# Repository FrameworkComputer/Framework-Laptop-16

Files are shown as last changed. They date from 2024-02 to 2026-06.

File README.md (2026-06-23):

# Framework Laptop 16
Documentation around the Mainboard and other key parts of Framework Laptop 16 
(available at https://frame.work/marketplace/mainboards).

We designed Framework Laptop 16 to enable re-use of key modules like the Mainboard.
The Mainboard is operable as a standalone single board computer outside of the laptop,
though with kind of a large form factor relative to Framework Laptop 13.

## License

Framework Laptop 16 © 2024 by Framework Computer Inc is licensed under CC BY 4.0.
To view a copy of this license, visit http://creativecommons.org/licenses/by/4.0/

## 3D CAD (in the base directory)

External 3D CAD of the system and main modules to enable development of 3D-printed replacement parts,
skins, cases, and other accessories.  We're excited to see what you do with it!

## Case

This folder contains a 3D printable case to reuse the Mainboard as a standalone computer.

## Mainboard

This folder contains 2D drawings and interface schematics to enable Mainboard re-use.

## Touchpad

This folder contains 3D printable CAD for single-piece replacement versions of the Touchpad row.

## Input Modules

See https://github.com/FrameworkComputer/InputModules

## Expansion Bay

See https://github.com/frameworkComputer/ExpansionBay

## Expansion Cards

See https://github.com/frameworkComputer/ExpansionCards

## Webcam

See https://github.com/FrameworkComputer/Framework-Laptop-13/tree/main/Webcam

## Display

Pinout of the Display to enable re-use.

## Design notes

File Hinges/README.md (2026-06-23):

Available at https://frame.work/products/16-hinge-kit

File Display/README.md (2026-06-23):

# Display

## License

Framework Laptop 16 © 2023-2026 by Framework Computer Inc is licensed under CC BY 4.0.
To view a copy of this license, visit http://creativecommons.org/licenses/by/4.0/

## Pinout

| Pin | Signal | Notes | Diff vs Laptop 13 |
|-----|---|---|---|
| 1 | DDS SCL | Nvidia DDS I2C SCL | Added |
| 2 | GND | Signal ground | |
| 3 | EDP_TXN_3 | | |
| 4 | EDP_TXP_3 | | |
| 5 | GND | Signal ground | |
| 6 | EDP_TXN_2 | | |
| 7 | EDP_TXP_2 | | |
| 8 | GND | Signal ground | |
| 9 | EDP_TXN_1 | | |
| 10  | EDP_TXP_1 | | |
| 11  | GND | Signal ground | |
| 12  | EDP_TXN_0 | | |
| 13  | EDP_TXP_0 | | |
| 14  | GND | Signal ground | |
| 15  | AUXP | | |
| 16  | AUXN | | |
| 17  | GND | Signal ground | |
| 18  | 3V_EDP | 3.3V typical | |
| 19  | 3V_EDP | 3.3V typical | |
| 20  | 3V_EDP | 3.3V typical | |
| 21  | 3V_EDP | 3.3V typical | |
| 22  | SELF_TEST | Self test enable | |
| 23  | GND | Digital ground | |
| 24  | GND | Digital ground | |
| 25  | GND | Digital ground | |
| 26  | GND | Digital ground | |
| 27  | EDP_HPD | Hot plug detect output | |
| 28  | GND | Backlight ground | |
| 29  | GND | Backlight ground | |
| 30  | GND | Backlight ground | |
| 31  | GND | Backlight ground | |
| 32  | BLK_OFF_N | 3.3V input | |
| 33  | BLK_PWM_LCD | 200Hz to 2kHz, 3.3V | |
| 34  | DDS SDA | Nvidia DDS I2C SDA | Added |
| 35  | PSR_EN# | Panel-Self-Refresh | Added |
| 36  | BL_POWER | 5V-21V | |
| 37  | BL_POWER | 5V-21V | |
| 38  | BL_POWER | 5V-21V | |
| 39  | BL_POWER | 5V-21V | |
| 40  | OD_EN | | Added |

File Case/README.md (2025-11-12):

# Framework Laptop 16 Case
This is a 3D-printable case to enable re-use of the Framework Laptop 16 Mainboard.

Note that you'll want to use filament that is designed for high temperatures, like ABS, PETG, or PP.

It is sized to be able to fit on the print bed of a Prusa XL, but there is also a split
version to enable smaller printers.

You'll need to print 8x of the "Connect Pin 1" to connect the top and bottom halves to each other.

If you're printing the split version, you'll also need 5x of the "Connect Pin 2".



## License

Framework Laptop 16 © 2024 by Framework Computer Inc is licensed under CC BY 4.0.
To view a copy of this license, visit http://creativecommons.org/licenses/by/4.0/

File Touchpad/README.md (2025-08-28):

# Touchpad


## License

Framework Laptop 16 © 2025 by Framework Computer Inc is licensed under CC BY 4.0.
To view a copy of this license, visit http://creativecommons.org/licenses/by/4.0/

## 3D CAD

This is 3D printable CAD of a single-piece alternative to the three-piece touchpad row
on Framework Laptop 16.
The best orientation to print this, is with the flat side (where the palms
would rest) on the bottom facing the printer bed.

You can directly unscrew the Touchpad Module itself and the daughterboard and screw them
into the 3D printed plastic parts.  Be careful not to over-tighten the fasteners, since
you can strip the plastic.

Make sure you align the Touchpad Module in the center of the opening.  You can do this easily
by screwing in one fastener, then flipping the assembly over, aligning it, and then holding it place,
flipping it back over, and screwing in the remaining fasteners.

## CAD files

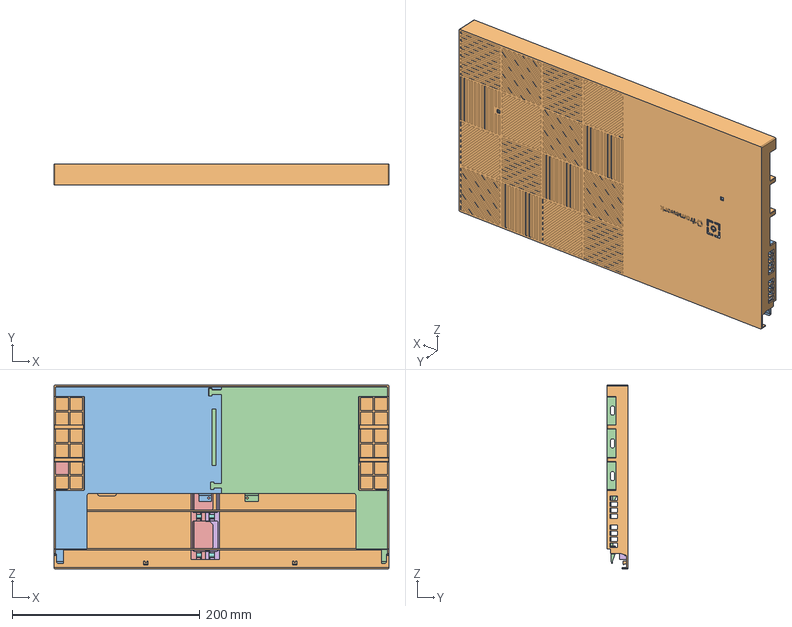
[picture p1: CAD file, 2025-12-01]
Case/mb_case_assy_11112025.stp
356.6 x 22.1 x 195.5 mm
MB_CASE_BOTTOM_COVER
MB_CASE_TOP_COVER
MB_CASE_BOTTOM_COVER_LEFT
MB_CASE_BOTTOM_COVER_RIGHT
MB_CASE_TOP_COVER_LEFT
MB_CASE_TOP_COVER_RIGHT
CONNECT_PIN_1 x 8
CONNECT_PIN_2 x 5

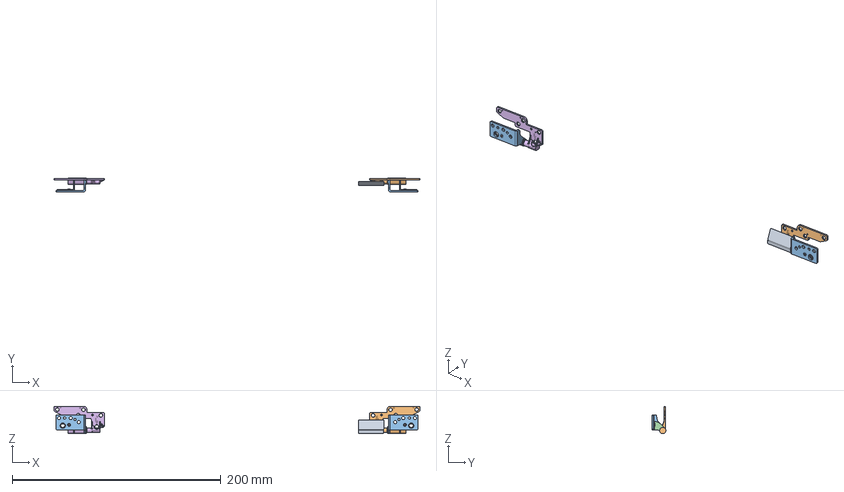
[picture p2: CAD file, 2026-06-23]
Hinges/framework_laptop_16_hinge_assy_asm.stp
350.4 x 13.2 x 26.2 mm
IFGP6_DISPLAY_ASSY_SKEL
IFGP6_LCD_BRACKET_R_3
IFGP6_BASE_BRACKET_R
IFGP6_BASE_BRACKET_R_2
IFGP6_HINGE_RIVET x 2
IFGP6_LCD_BRACKET_L
IFGP6_BASE_BRACKET_L
IFGP6_BASE_BRACKET_L_2

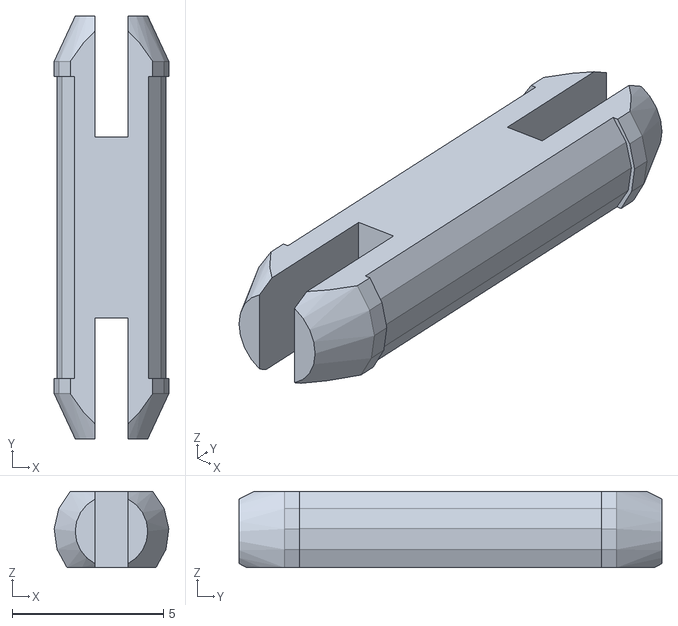
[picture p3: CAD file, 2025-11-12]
Case/Full version/connect_pin_1_11112025.stl
3.80 x 14.0 x 2.52

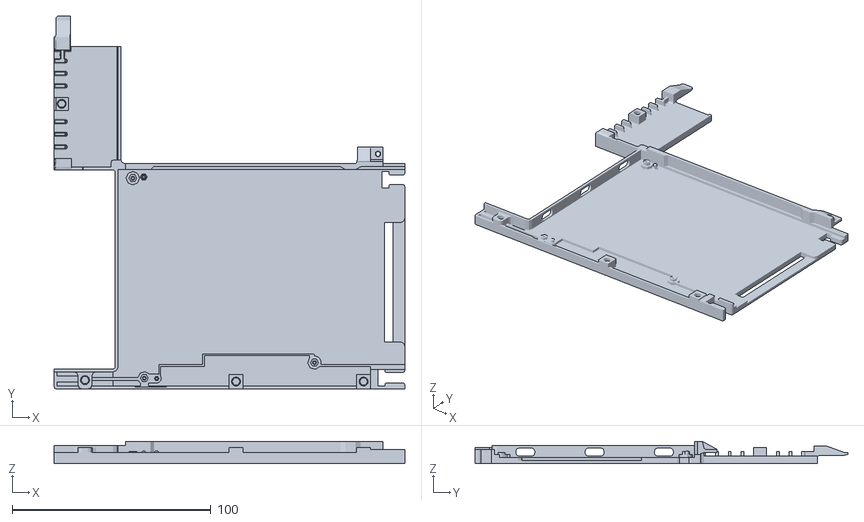
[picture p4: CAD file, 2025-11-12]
Case/Split verstion/mb_case_bottom_cover_left_11112025.stl
176.6 x 187.9 x 11.2

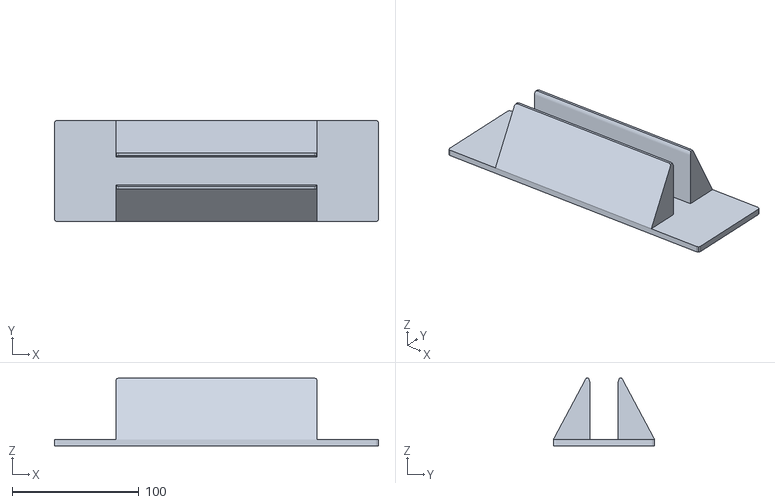
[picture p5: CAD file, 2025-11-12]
Case/Stand/mbcase_id_stand_11112025.stl
255.7 x 80.0 x 53.5

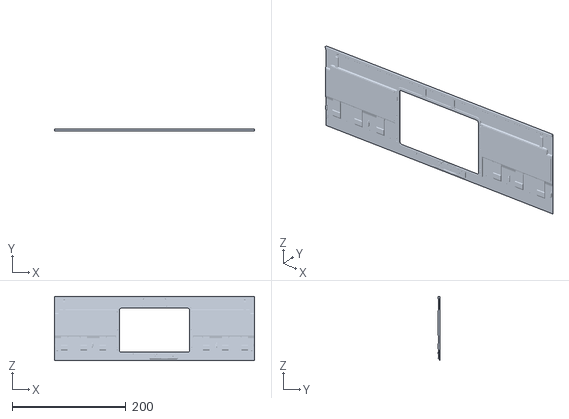
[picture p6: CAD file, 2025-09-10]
Touchpad/one_piece_tp_mid_0909.stl
351.6 x 3.15 x 112.6

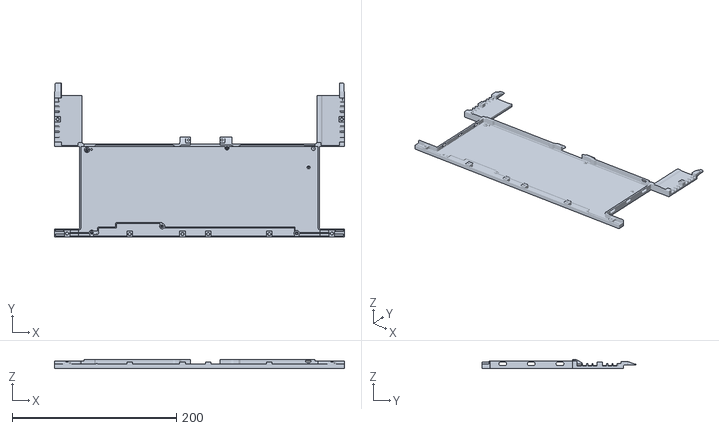
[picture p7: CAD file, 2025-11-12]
Case/Full version/mb_case_bottom_cover_11112025.stl
353.2 x 187.9 x 11.2

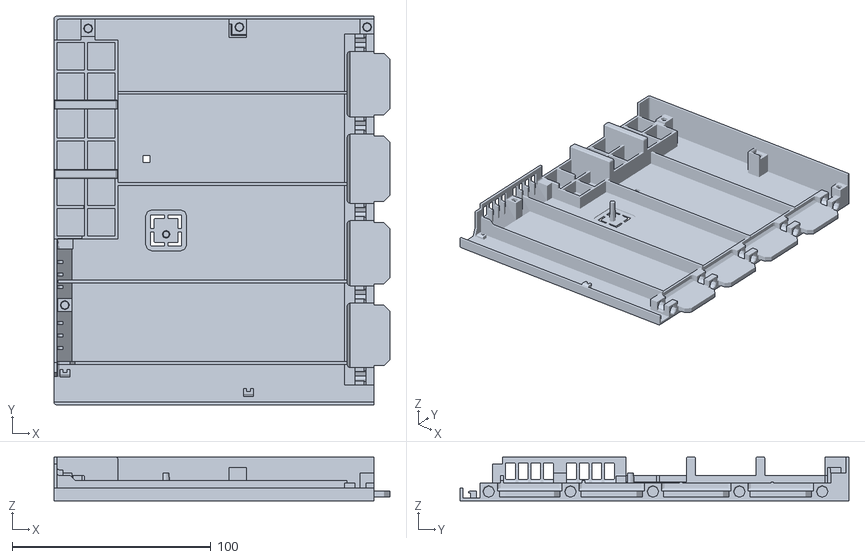
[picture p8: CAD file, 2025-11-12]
Case/Split verstion/mb_case_top_cover_left_11112025.stl
169.1 x 195.5 x 22.0

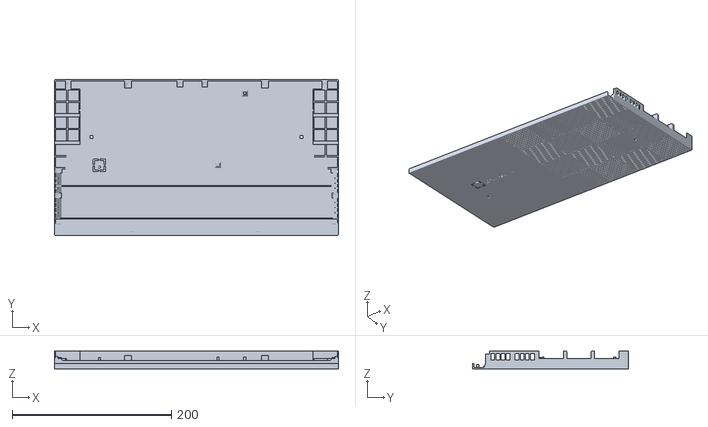
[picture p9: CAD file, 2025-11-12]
Case/Full version/mb_case_top_cover_11112025.stl
356.6 x 195.5 x 22.0

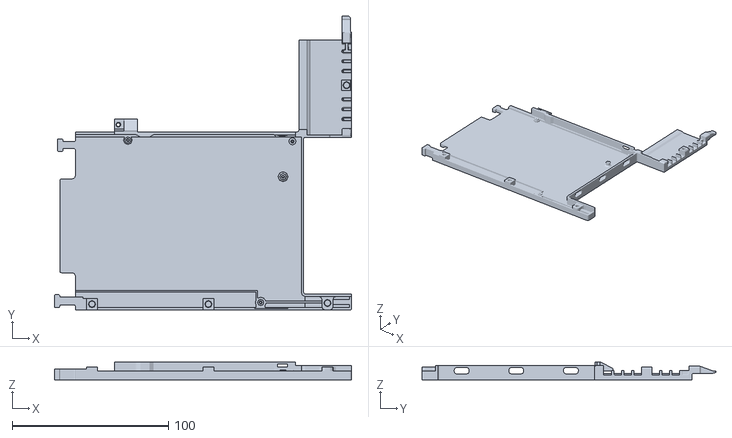
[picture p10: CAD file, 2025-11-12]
Case/Split verstion/mb_case_bottom_cover_right_11112025.stl
190.1 x 187.9 x 11.2

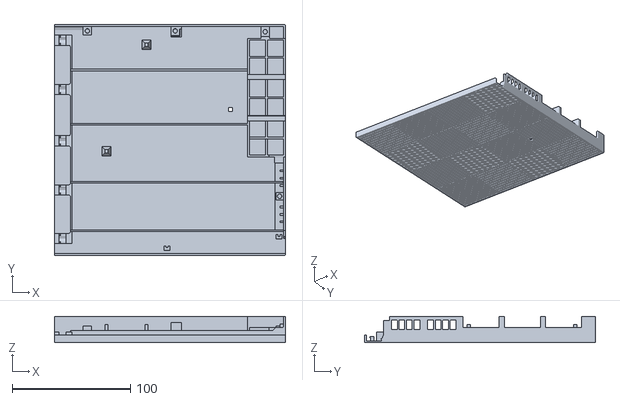
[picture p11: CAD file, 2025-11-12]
Case/Split verstion/mb_case_top_cover_right_11112025.stl
195.5 x 195.5 x 22.0

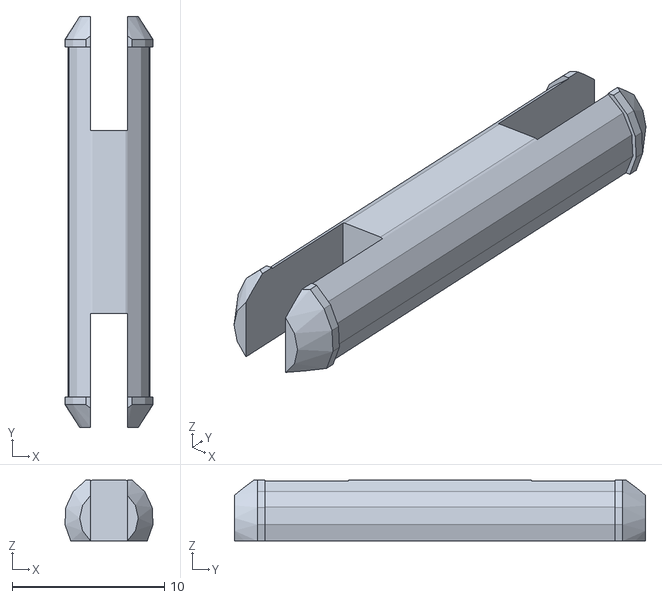
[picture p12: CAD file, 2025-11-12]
Case/Split verstion/connect_pin_2_11112025.stl
5.79 x 27.0 x 4.00

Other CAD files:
Touchpad/one_piece_tp_right_0909.stl
Touchpad/one_piece_tp_left_0909.stl

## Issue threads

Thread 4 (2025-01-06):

Errors in PDF USB Section

hasechris, 2025-01-06:
Hi,

I just looked at the first block level schematic for like an hour and then saw something which I find quite confusing. Please see the image here:

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

Why are only CC-Line Connections mentioned for one USB-C Port? I thougth the PD Controllers would have to be connected to the 4 USB-C Ports which support Power Delivery.

Best regards
hasechris

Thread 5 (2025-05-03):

Framework 16 Panel Pinout Not Documented

ThatWileyGuy, 2025-05-03:
The Framework 13 panel-side eDP pinout is documented at https://github.com/FrameworkComputer/Framework-Laptop-13/blob/main/Display/README.md

I cannot find an equivalent for the Framework 16. I do see the mainboard-side pinout in https://github.com/FrameworkComputer/Framework-Laptop-16/blob/main/Mainboard/Mainboard_Interfaces_Schematic_Framework_Laptop_16_7040_Series.pdf , but it doesn't look like the panel-side pinout is documented?

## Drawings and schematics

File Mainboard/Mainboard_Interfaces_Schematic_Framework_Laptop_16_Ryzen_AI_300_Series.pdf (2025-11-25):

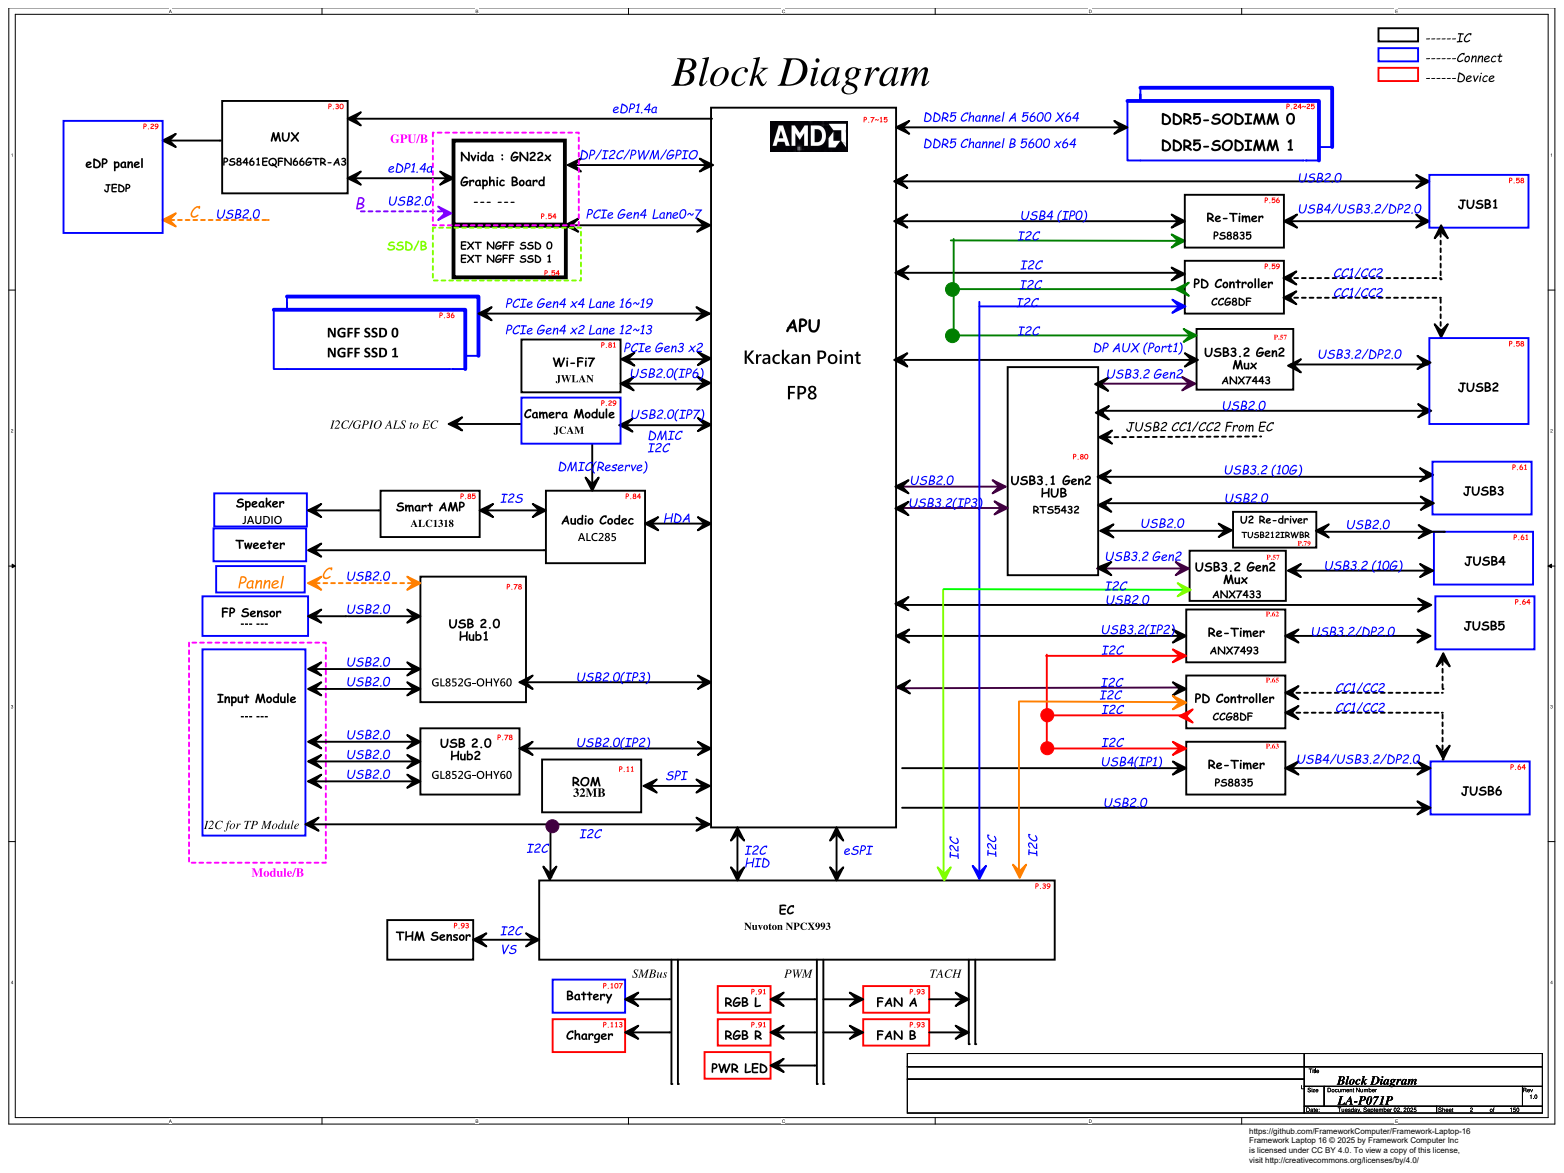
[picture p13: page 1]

https://github.com/FrameworkComputer/Framework-Laptop-16
Framework Laptop 16 © 2025 by Framework Computer Inc
is licensed under CC BY 4.0. To view a copy of this license,
visit http://creativecommons.org/licenses/by/4.0/

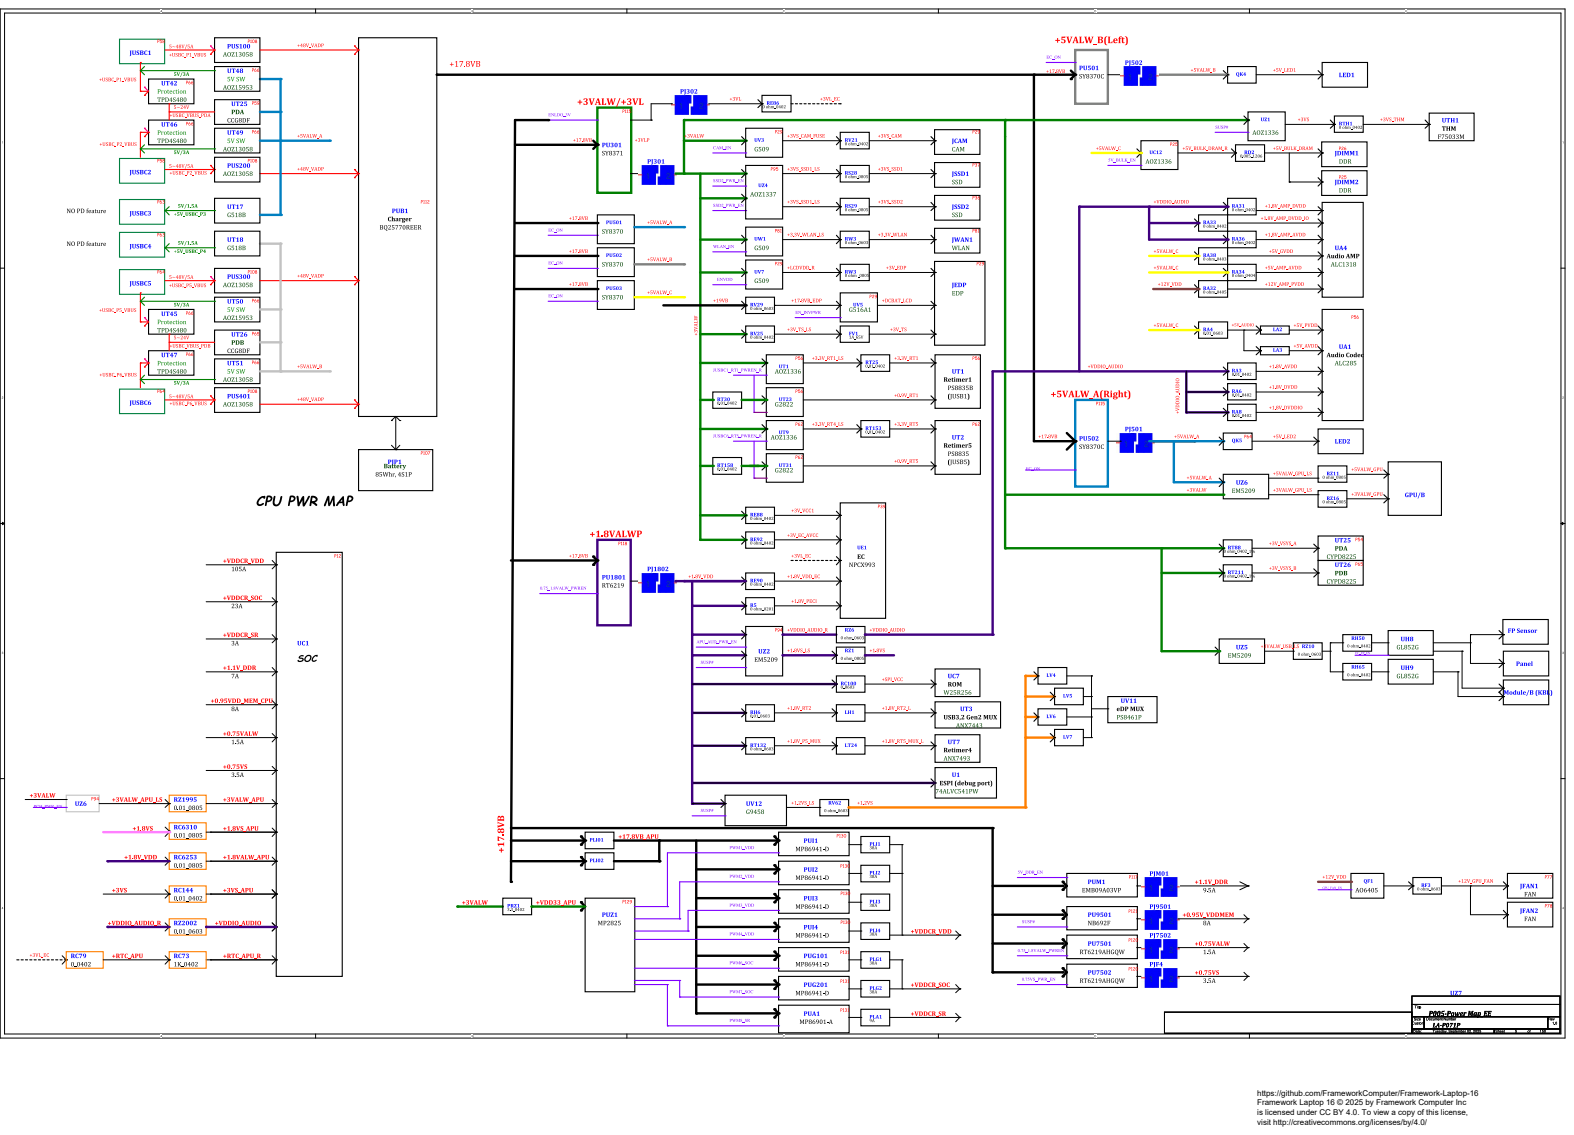
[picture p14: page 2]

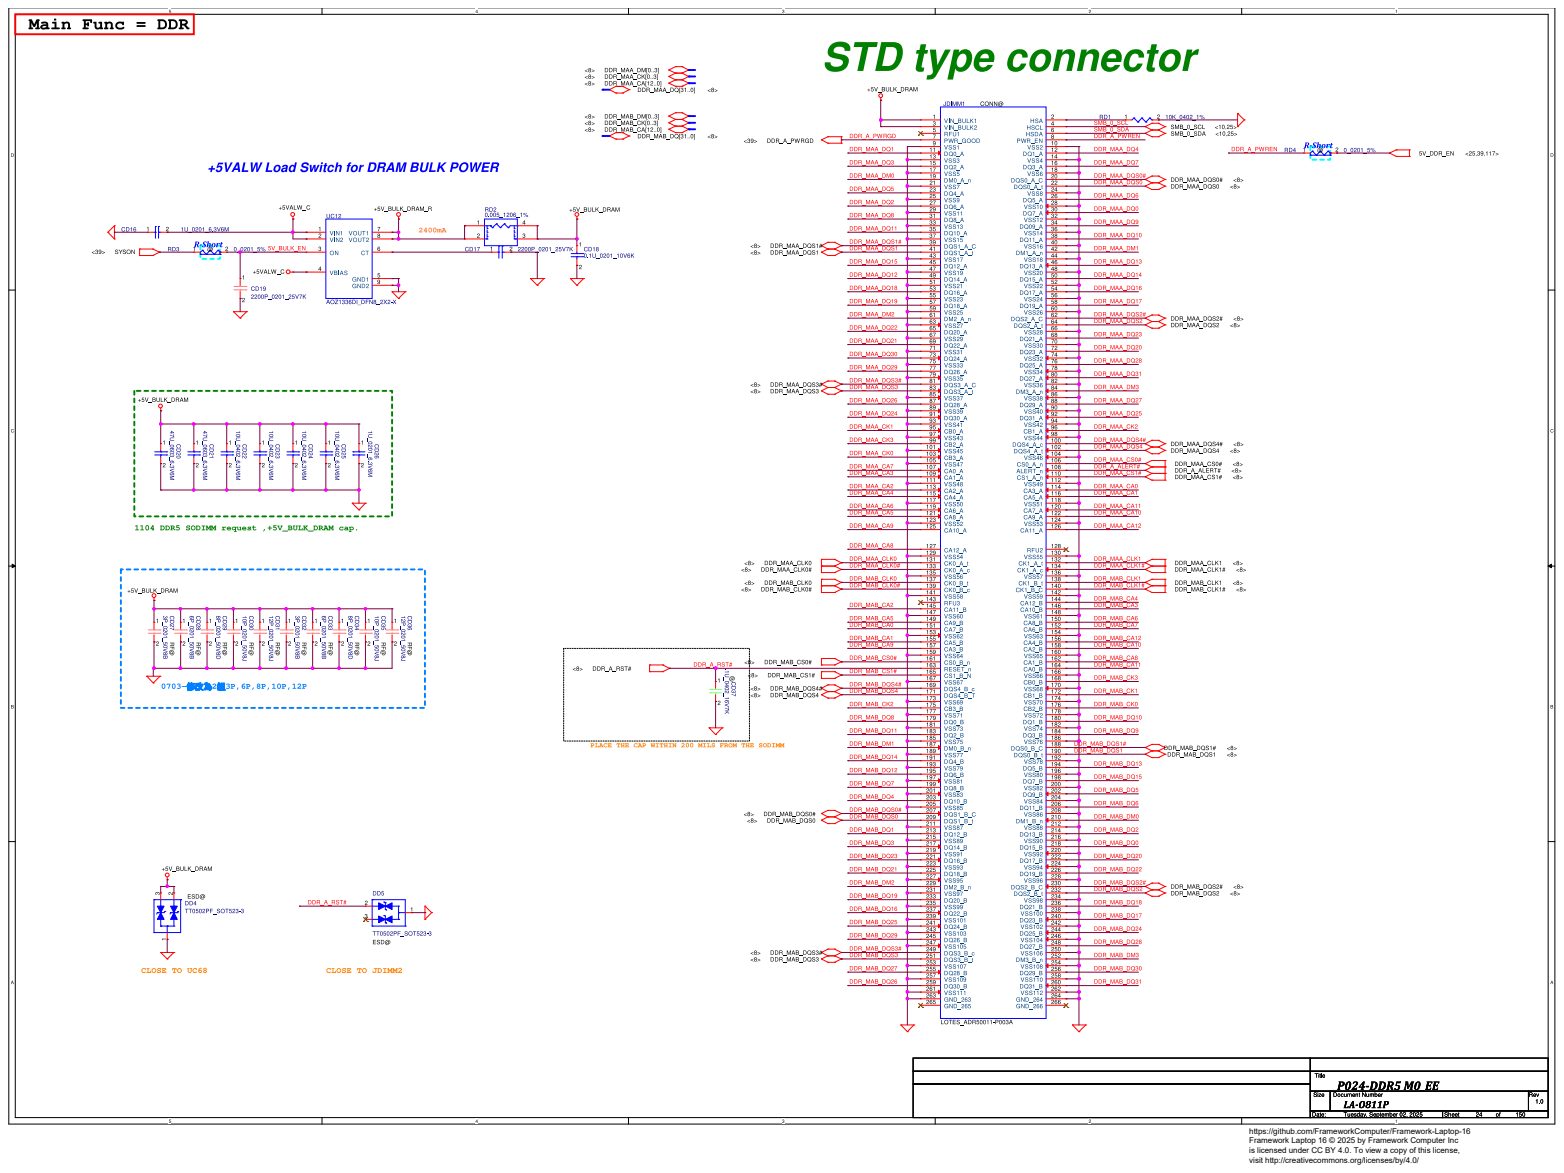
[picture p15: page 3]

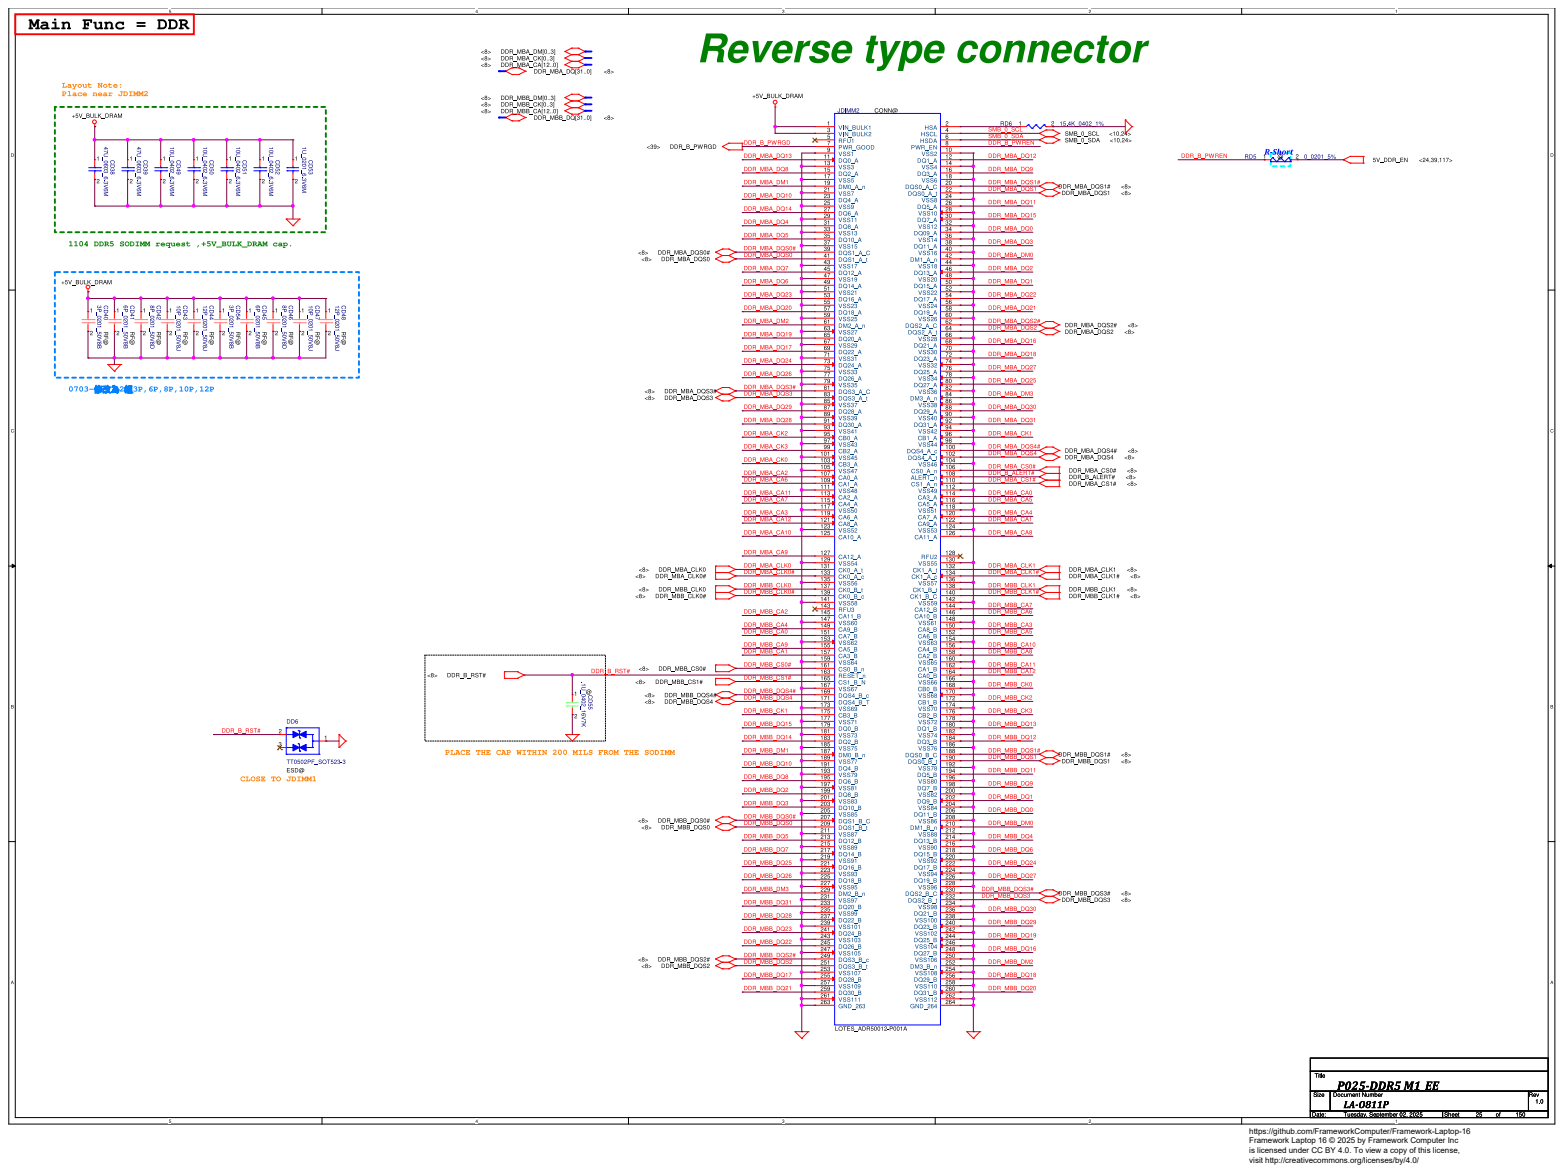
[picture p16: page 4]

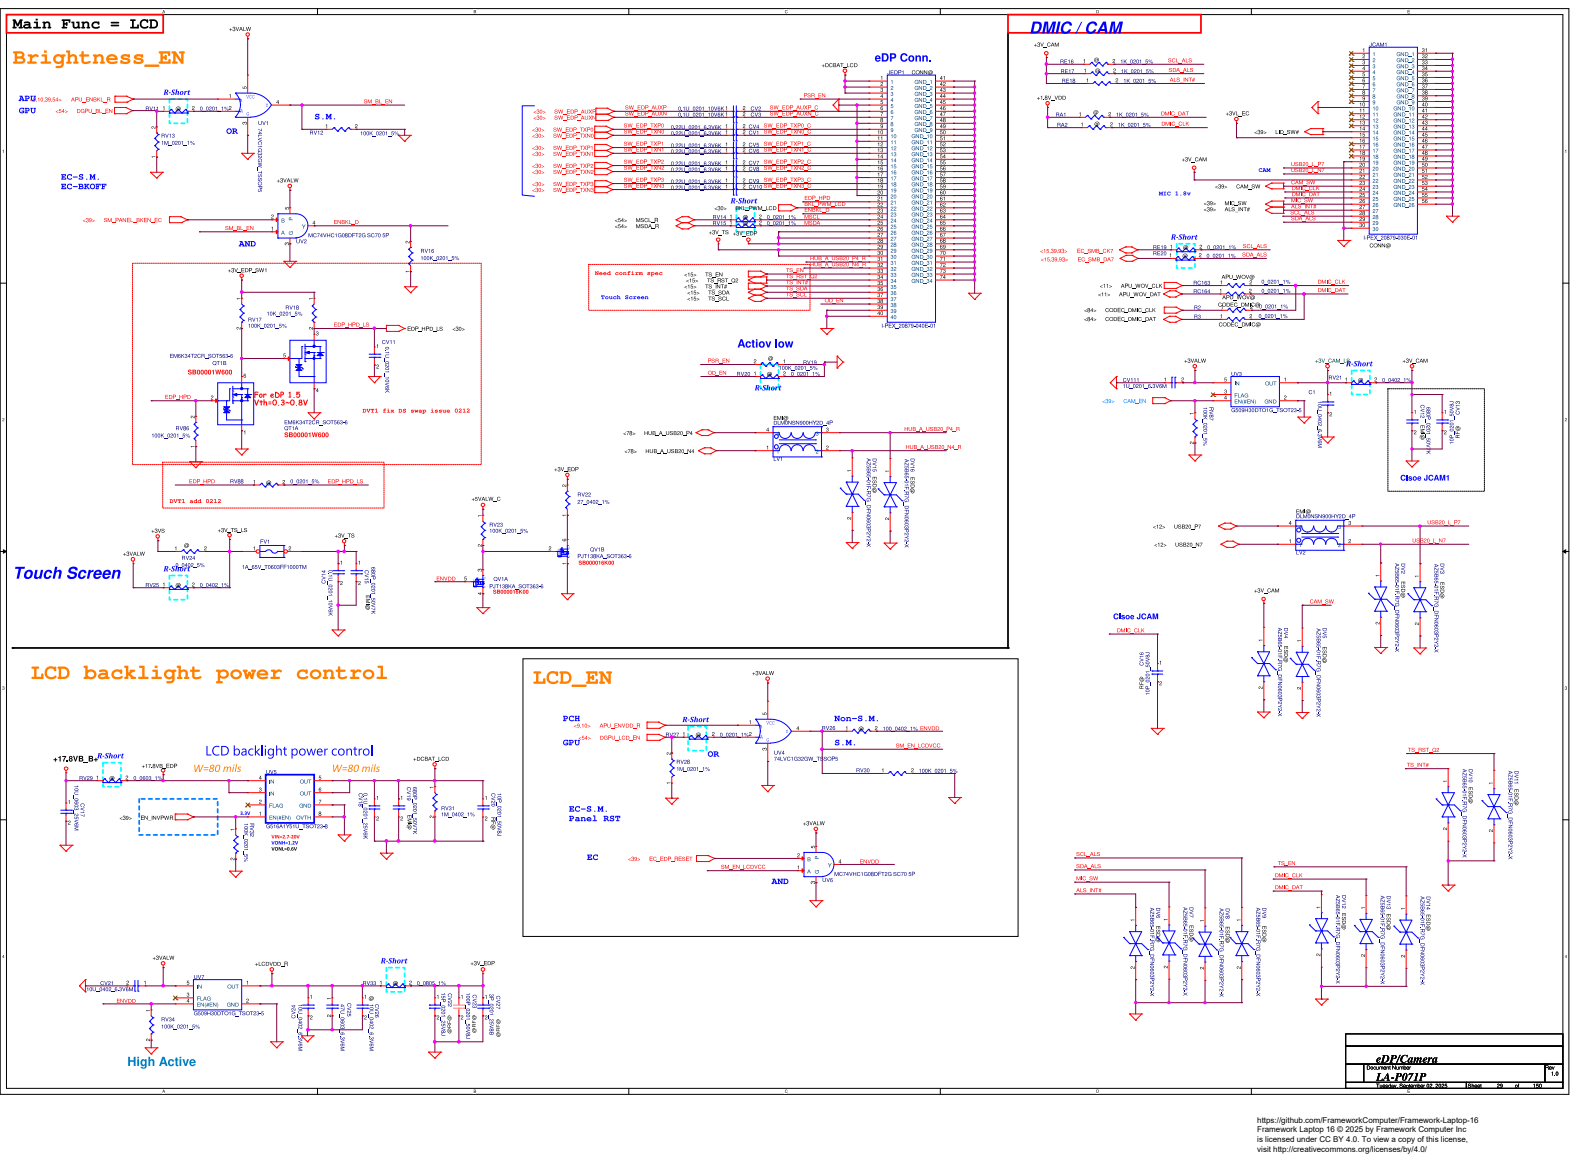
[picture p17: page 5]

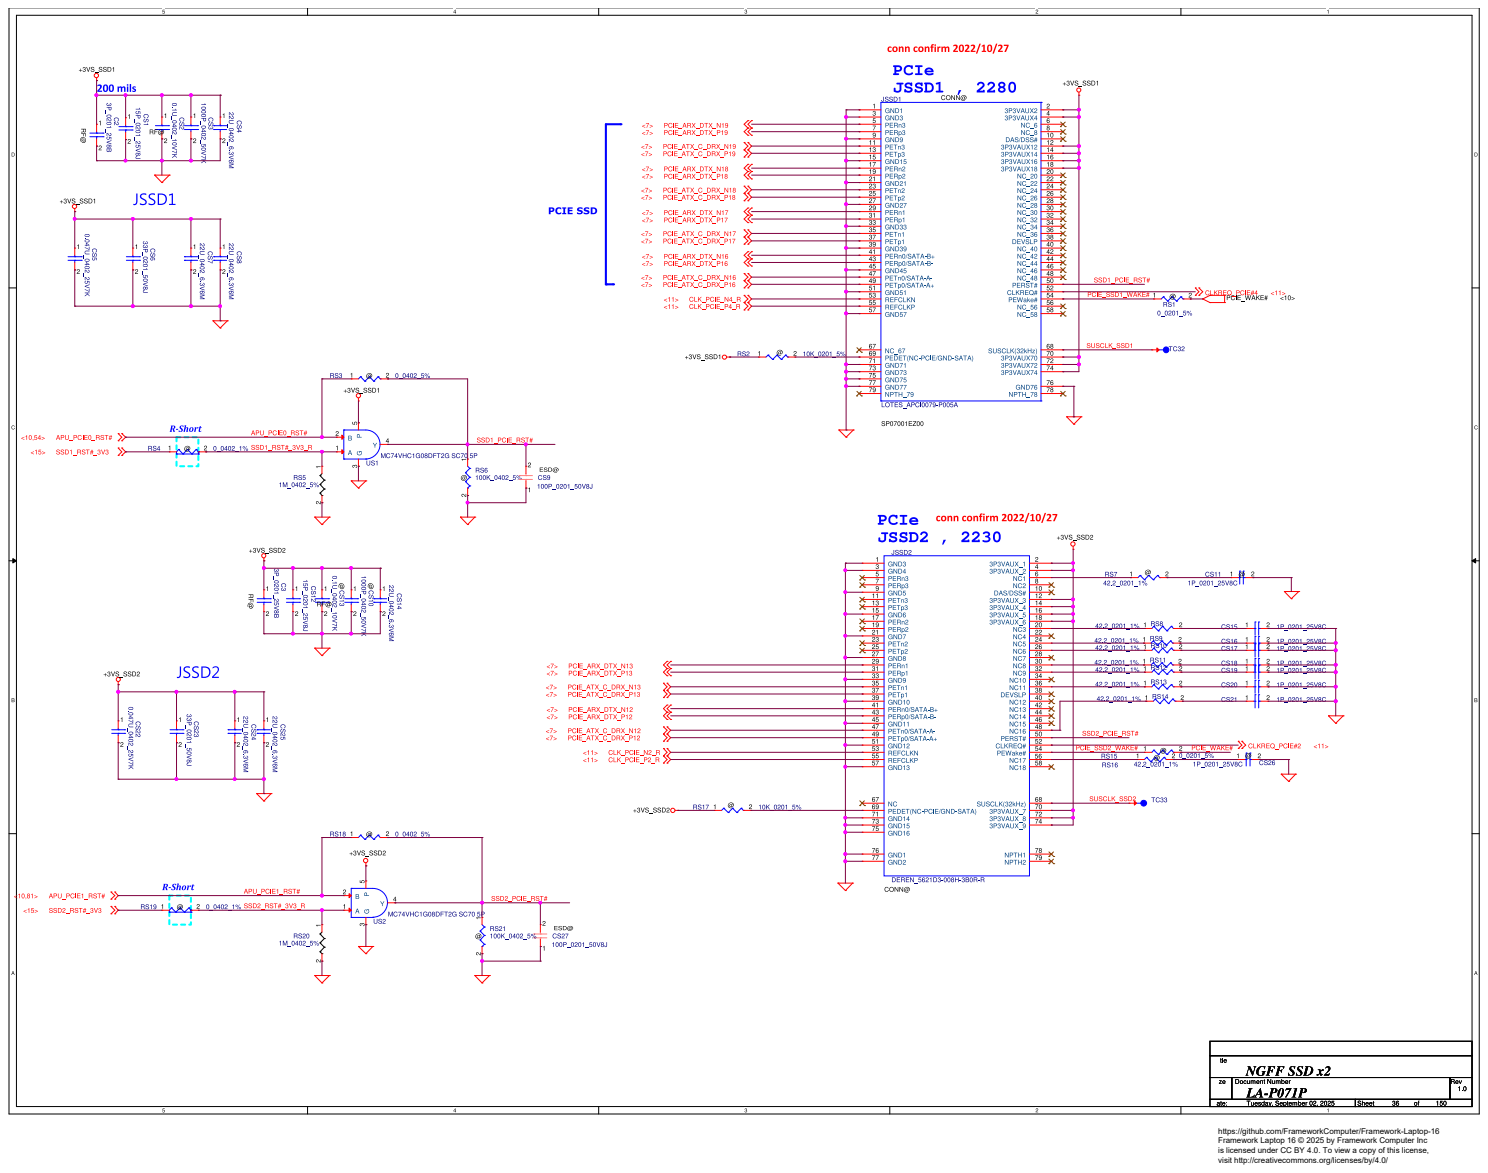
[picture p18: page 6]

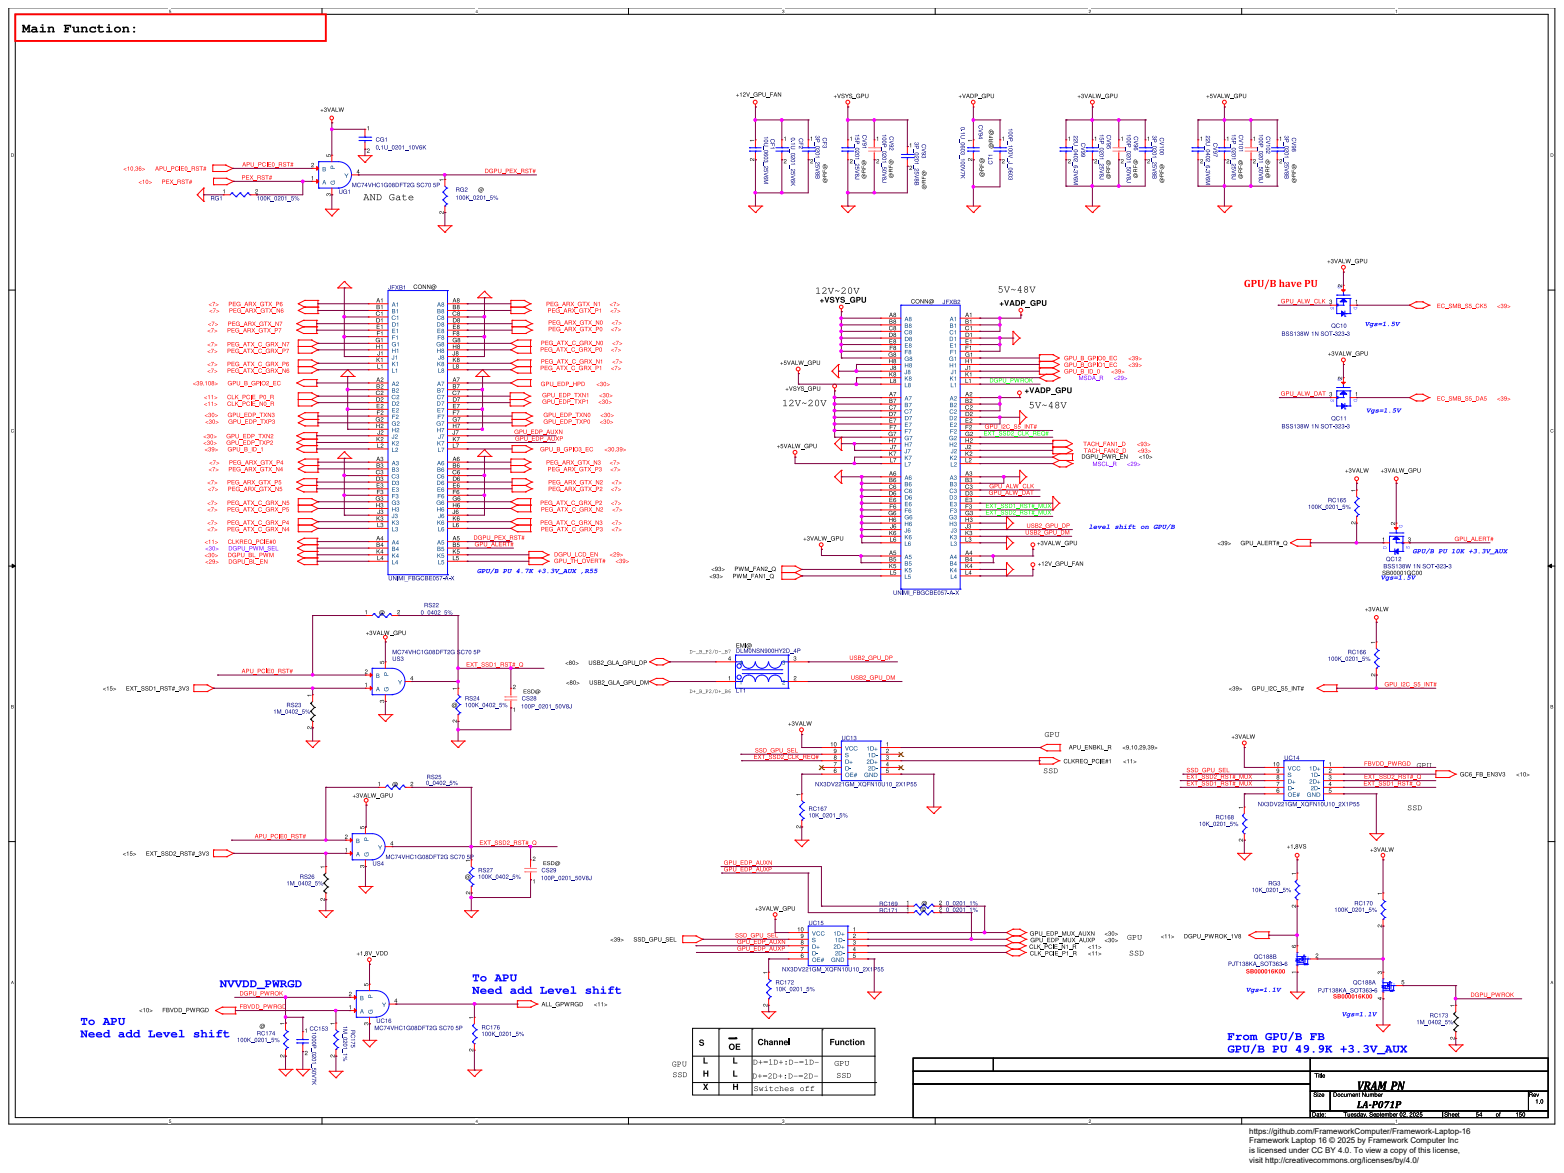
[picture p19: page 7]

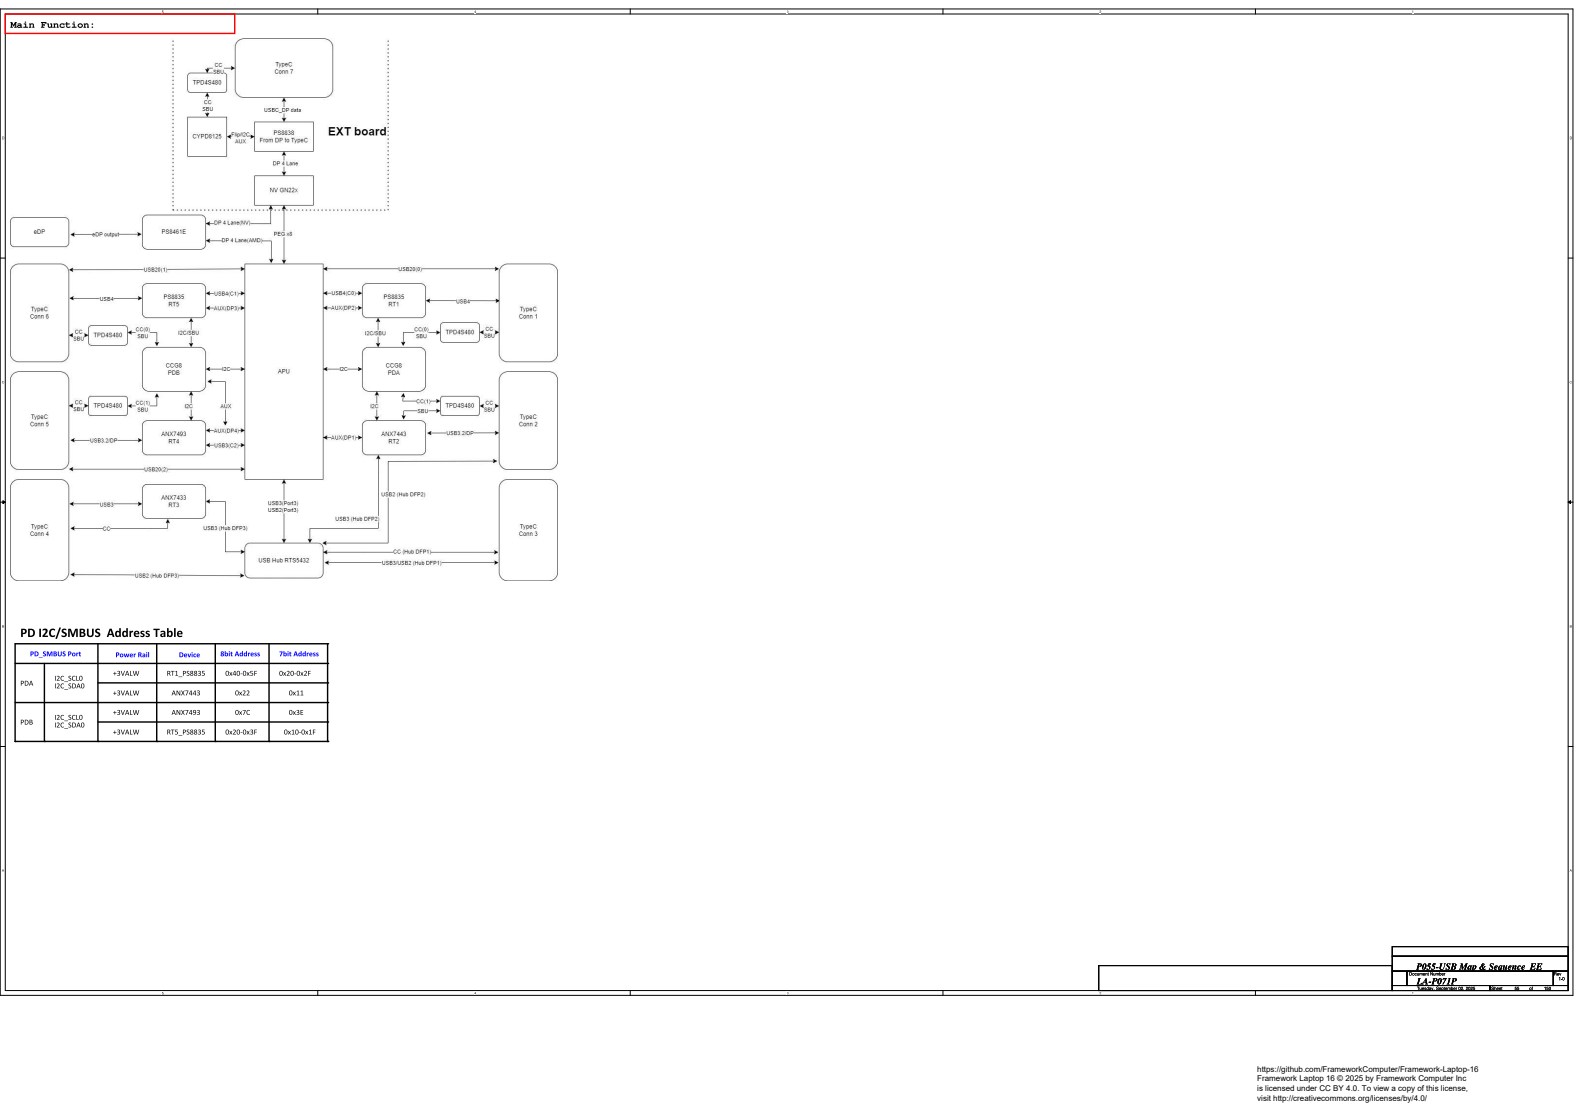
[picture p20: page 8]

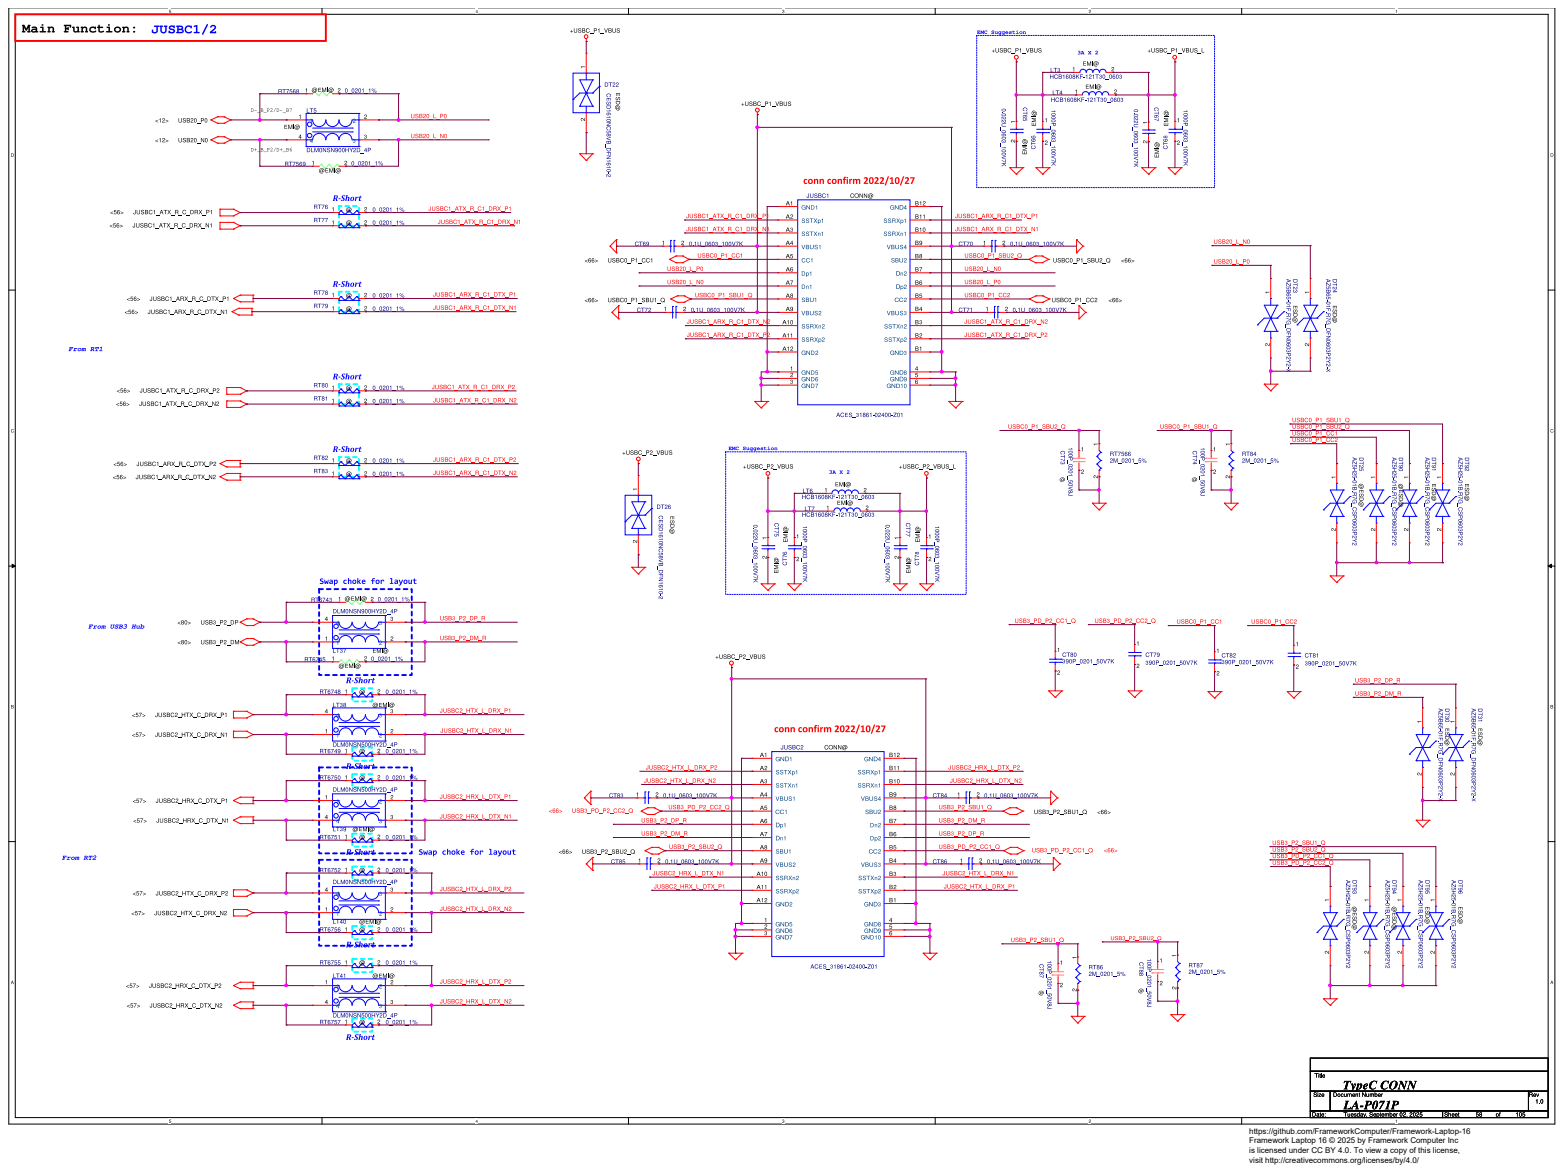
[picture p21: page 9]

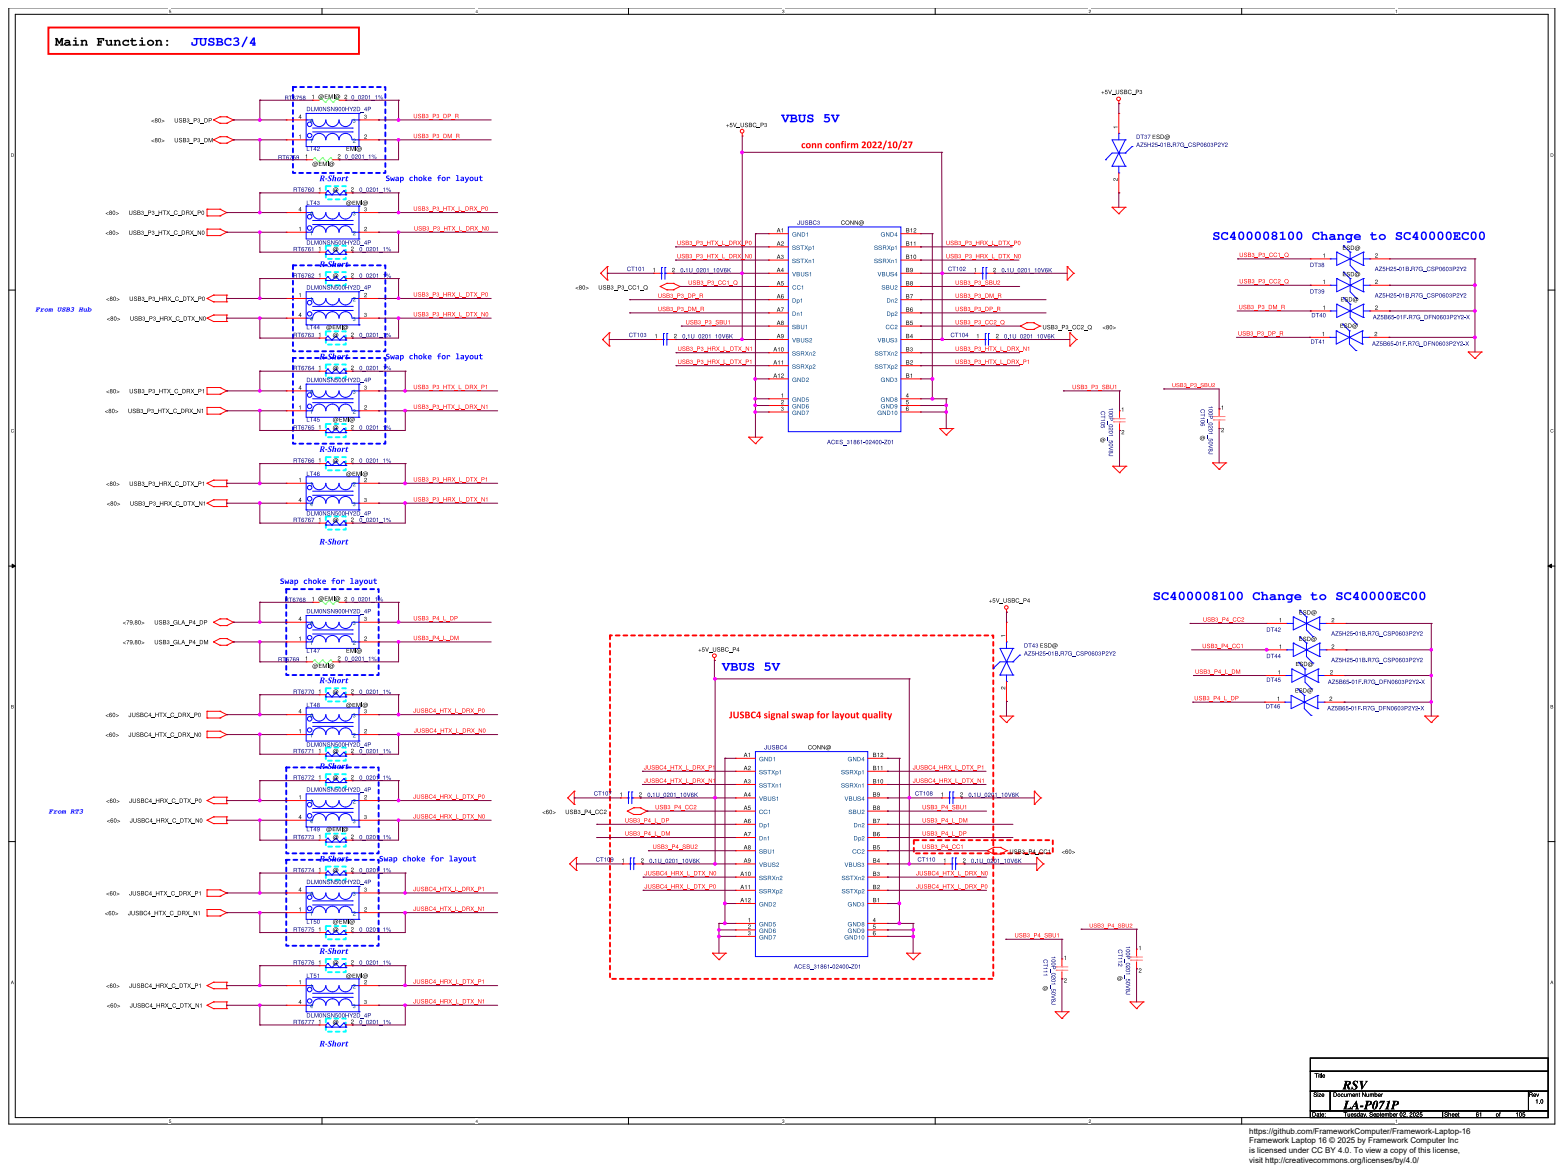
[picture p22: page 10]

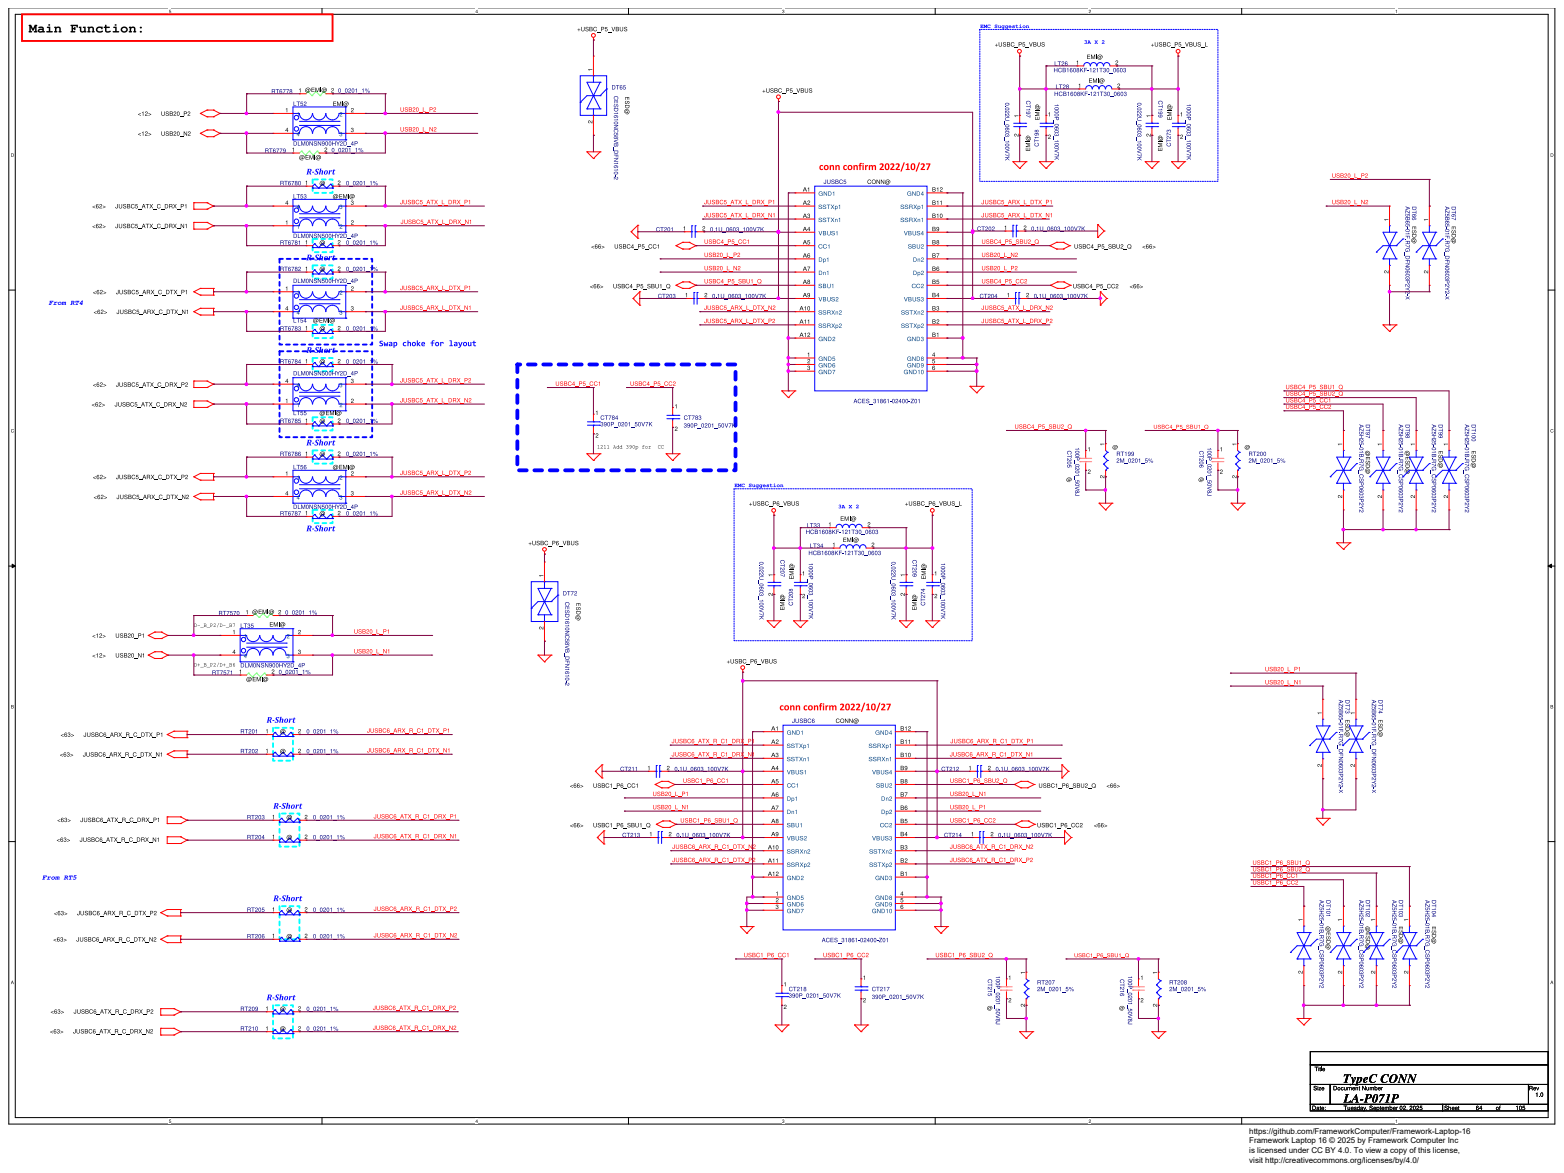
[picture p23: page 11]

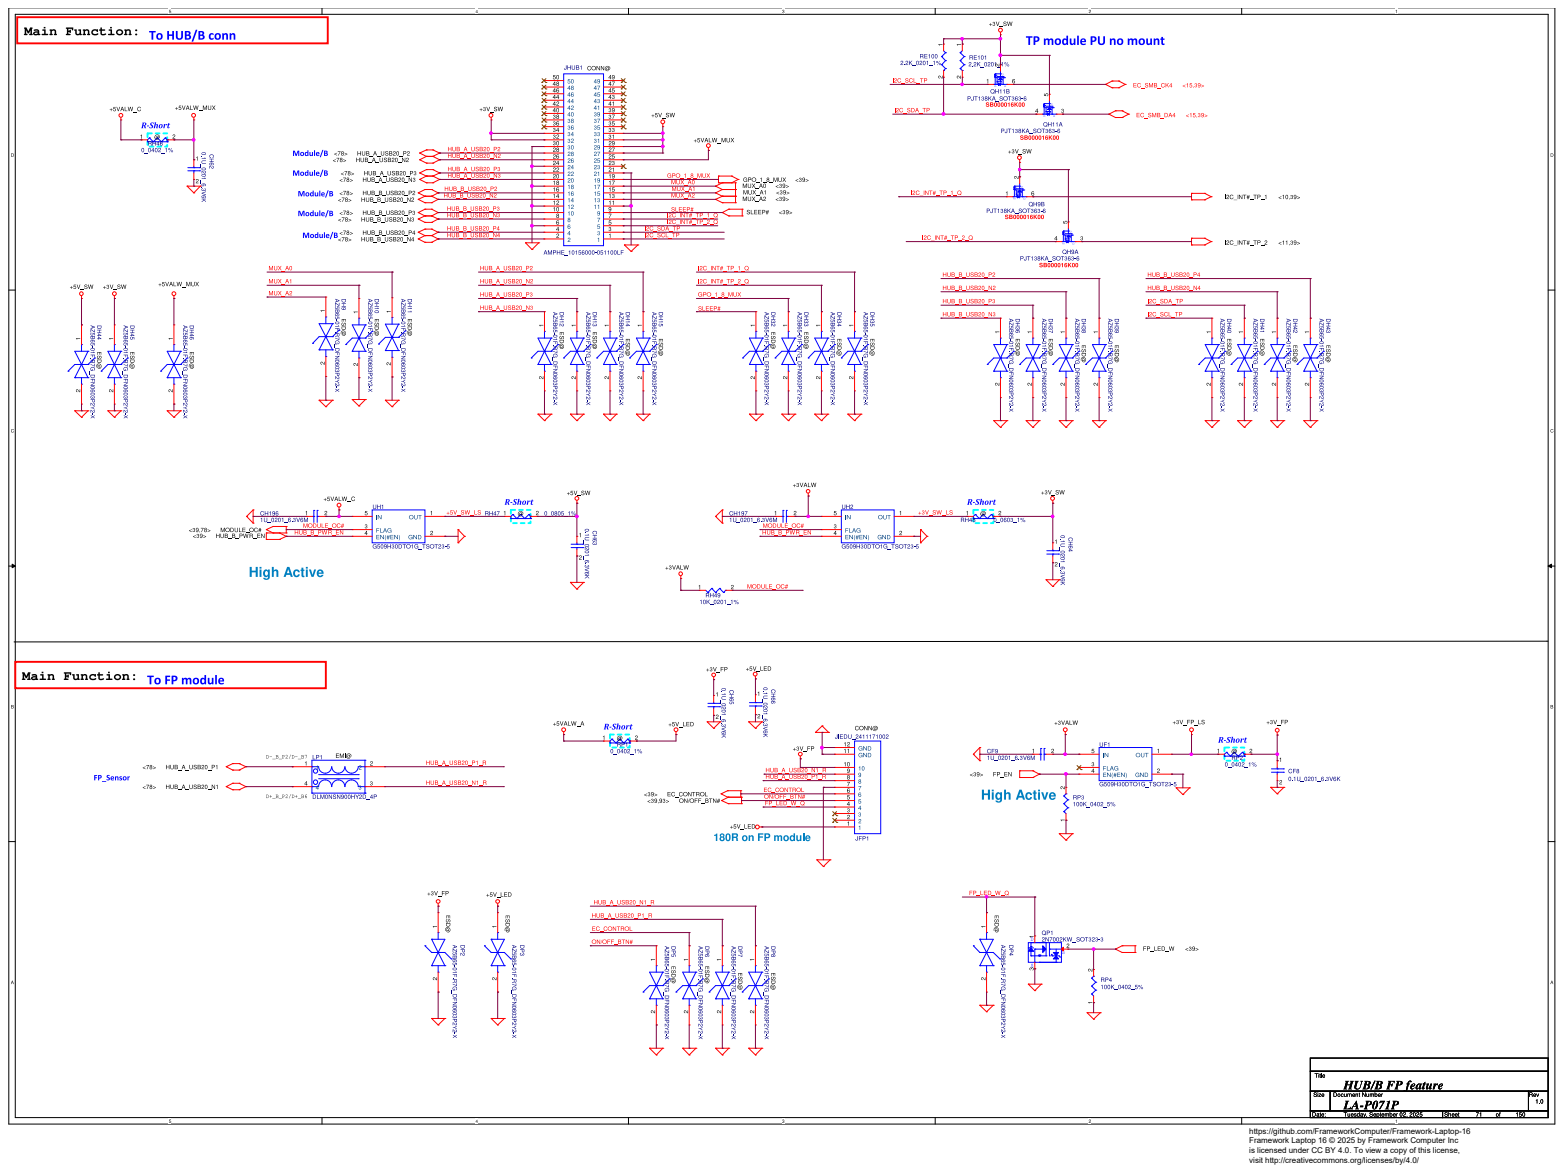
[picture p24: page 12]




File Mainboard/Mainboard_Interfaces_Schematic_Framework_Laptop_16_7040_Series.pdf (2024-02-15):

# eDP1.4

P.6~14

I2C HID; Block Diagram; PCIe Gen4; PS8461EQFN66GTR-A3; DP/I2C/PWM/GPIO; MUX; USB2.0; Pannel; Lane0~7; eDP1.4a; SMBus; Re-Timer; Input Module --- ---; NGFF SSD 1; ROM 32MB; eSPI; RGB L; PWM; TACH; NGFF SSD 0; AMD:R23M; Graphic Board; CCG8DF; Nuvoton NPCX993; Battery; USB 2.0 Hub2; JEDP; Phoenix FP7r2; NPCT750AADYX; JAUDIO; GPU/B; TPM; SPI; ------Device; ------Connect; Audio Codec; USB2.0(IP7); JCAM; Tweeter; JWLAN; HDA; ALC295; Speaker; Smart AMP; ALC1318; DMIC I2C; PCIe Gen2; Camera Module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

EXT NGFF SSD 0
EXT NGFF SSD 1

I2C/GPIO ALS to EC

I2C for TP Module
Module/B

https://github.com/FrameworkComputer/Framework-Laptop-16
Framework Laptop 16 © 2024 by Framework Computer Inc
is licensed under CC BY 4.0. To view a copy of this license,
visit http://creativecommons.org/licenses/by/4.0/

## +5VALW_A

## +3VALW


HUB_B_PWR_EN
+3VALW
https://github.com/FrameworkComputer/Framework-Laptop-16
Framework Laptop 16 © 2024 by Framework Computer Inc
is licensed under CC BY 4.0. To view a copy of this license,
visit http://creativecommons.org/licenses/by/4.0/

# Main Function:GPU

## 5V~48V 12V~20V


https://github.com/FrameworkComputer/Framework-Laptop-16

level shift on GPU/B

To APU
Need add Level shift

# Main Func = LCD

# Brightness_EN

High Active; Touch Screen; eDP Conn.; CAM; MIC 1.8v; DMIC / CAM; Clsoe JCAM1; Clsoe JCAM; SCA00004320; APU GPU; EC-S.M. EC-BKOFF; PCH; GPU; LCD_EN; Non-S.M.; EC-S.M. Panel RST; Actiov low; AND; VONL=0.6V; VONH=1.2V; VIN=2.7-20V; W=80 mils; EDP_HPD; TS_RST_Q; TS_INT#; TS_SDA; TS_SCL; BKL_PWM_LCD; CAM_SW; MIC_SW; USB20_P7; USB20_N7; ALS_INT#; HUB_A_USB20_N4; HUB_A_USB20_P4; APU_WOV_CLK; CODEC_DMIC_CLK; APU_WOV_DAT; CODEC_DMIC_DAT; LID_SW#; EN_INVPWR; MSCL_R; MSDA_R; CAM_EN; +3VALW; +LCDVDD_R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

Need confirm spec

LCD backlight power control

https://github.com/FrameworkComputer/Framework-Laptop-16

# Main Func = WLAN M.2

Place near Pin 2,4 | Place near Pin 72,74

E Key CONN; 80 mils; High Active; 6/30 add; conn change 2022/09/07; Input; Output; PLDR; WLAN_EN; EC_UART0_TX; EC_UART0_RX; TDM2_DOUT; TDM2_FRM; TDM2_DIN; TDM2_BCLK; USB20_N6; USB20_P6; +3.3V_WLAN; +3VALW; +1.8V_VDD; +3.3V_WLAN_LS; APU_PCIE1_RST#; WL_RST#; UART_0_RTS#; UART_0_ATXD_DRXD; UART_0_ARXD_DTXD; UART_0_CTS#; PCIE_CTX_C_DRX_P15; PCIE_CTX_C_DRX_N15; PCIE_CRX_DTX_P15; PCIE_CRX_DTX_N15; CLK_PCIE_P6_R; CLK_PCIE_N6_R; CLKREQ_PCIE#6; WLAN_WAKE#; SUSCLK_WLAN; UART_0_ARXD_R_DTXD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

For modern standby

reserved for UART

https://github.com/FrameworkComputer/Framework-Laptop-16

# Main Func = Battery LED

## SC50000EI00

W=10mil; W=20mil; TYPEC_B_DRV; TYPEC_G_DRV; TYPEC_R_DRV; LEFT_SIDE; RIGHT_SIDE; +5V_LED1; +5V_LED2; +5VALW_B; +5VALW_A; 2N7002KW_SOT323-3; LED2; LTST-S33FBEGW-SN_RGB; LED1; QK5 AO3413_SOT23; QK7 AO3413_SOT23; QK2 2N7002KW_SOT323-3 2; QK1B PJT138KA_SOT363-6 ⁶; QK3B PJT138KA_SOT363-6 ⁶; QK1A PJT138KA_SOT363-6 5; QK4 2N7002KW_SOT323-3 2; QK3A PJT138KA_SOT363-6 5; +TYPEC_R_DRV1_Q; +TYPEC_R_DRV2_Q; +TYPEC_B_DRV1_Q; +TYPEC_G_DRV1_Q; +TYPEC_B_DRV2_Q; +TYPEC_G_DRV2_Q

Left TBT LED

Right TBT LED

https://github.com/FrameworkComputer/Framework-Laptop-16

# PCIe JSSD1 , 2280

JSSD1; JSSD2; 200 mils; PCIE SSD; conn confirm 2022/10/27; PCIe JSSD2 , 2230; PCIE_WAKE#; +3VS_SSD1; +3VS_SSD2; CLKREQ_PCIE#4; CLK_PCIE_N4_R; CLK_PCIE_P4_R; PCIE_CTX_C_DRX_N19; PCIE_CTX_C_DRX_P19; PCIE_CRX_DTX_N19; PCIE_CRX_DTX_P19; PCIE_CRX_DTX_N16; PCIE_CRX_DTX_P16; PCIE_CTX_C_DRX_N16; PCIE_CTX_C_DRX_P16; PCIE_CRX_DTX_N17; PCIE_CRX_DTX_P17; PCIE_CTX_C_DRX_N17; PCIE_CTX_C_DRX_P17; PCIE_CRX_DTX_N18; PCIE_CRX_DTX_P18; PCIE_CTX_C_DRX_N18; PCIE_CTX_C_DRX_P18; SSD2_RST#_LS; APU_PCIE0_RST#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

https://github.com/FrameworkComputer/Framework-Laptop-16

# Main Function: To HUB/B conn
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

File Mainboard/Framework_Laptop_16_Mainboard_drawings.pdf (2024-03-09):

1

2

DDR5 Top; mount_REV; REV; DESCRIPTION OF CHANGE; DATE; PART NUMBER; DESCRIPTION; SPECIFICATION; MODEL; SIZE; SHEET; REVISION; VERSION; UNLESS SPECIFIED TOLERANCE ARE:; 300 ABOVE :; 20mm BELOW :; ANGLES :; FLATNESS :; CONCENTRICITY :; Top view; SCALE 1.000; CONN LIST

Item | Function | COMPAL P/N | Description | Supplier | Qty | Rework
1 | Battery Conn | DC04000OI00 | SOCKET BATT BTJ-08TFBRAB 8P | OCTEKCONN | 1
2 | EDP Conn | SP01002U400 | S H-CONN IPEX 20879-040E-01 40P P0.4 | IPEX | 1
3 | Camera Conn | SP01002VR00 | S H-CONN IPEX 20879-040E-01 30P P0.4 | IPEX | 1
4 | SpeakerConn | LTCX00BFT00 | S SOCKET ACES 51220-00801-P01 8P H1.45 WTB P1.2 S | ACES | 1
5 | Hub Board Conn | SP010037W00 | S H-CONN AMPHENOL 10156000-051100LF 50P P0.5 | Amphenol | 1
6 | FP/ Power conn | SP010033M00 | S H-CONN JIEDUN 2411171002 10P P0.5 | JIEDUN | 1
7 | DDR5 Top mount_STD | SP07001WG00 | S SOCKET DEREN 567YD2-001H1S11R-R DDR5 | DEREN | 1
8 | | SP07001WH00 | S SOCKET DEREN 567YD2-001H1R11R-R DDR5 | DEREN | 1
9 | 2280 SSD KEY M | SP07001EZ00 | S SOCKET LOTES APCI0079-P005A 67P NGFF | LOTES | 1
10 | 2230 SSD KEY M | SP07001WJA0 | S SOCKET DEREN 5621D3-008H-3B0R-R NGFF | DEREN | 1
11 | WIFI KEY E | SP070011H00 | S SOCKET LOTES APCI0128-P005A 67P M_PCI | LOTES | 1
12 | USB type c | SP06000HTA0 | S CONN ACES 31861-0240D-003 USB | ACES | 6
13 | RTC BATT | SP02001SC00 | S W-CONN HEFENG AWB05-S02FCA-RB 2P P1.25 | HEFENG | 1
14 | Fbeam Standoff | ES00000NY00 | STANDOFF 0.6H 4.0 1.1H 2.5D M2.0 A | Ronnie | 2
15 | Wlan Standoff | ES00000J300 | STANDOFF 1.4H 5.0D 2.0H 4D M2.0 C | Ronnie | 1
16 | SSD Standoff | ES00000O100 | STANDOFF 1.4H 5.0D 0.8H 1.0D M1.4 A | Ronnie | 1
17 | MB Support Standoff | ES00000O000 | STANDOFF 4.6H 4.0D 1.0H 3.0D M2.0 A | Ronnie | 2
18 | Thermal Standoff | ES00000ON00 | STANDOFF 3.0H 4.0D 0H 0D M2.0 E | Ronnie | 1
19 | Antenna Standoff | ES00000OL00 | STANDOFF 2.9H 1.6D 0.8H 4.0D 4.0D F | Ronnie | 1
20 | Power Switch | SN111002700 | S TACT SW ACY25 EVQPLHA15 SPST | Panasonic | 1

DC04000QA00 | SOCKET BATT 570821-001H 8P | DEREN

SP01002X700 | S H-CONN HEFENG AFC42-S10FKA-R0 10P P0.5 | HEFENG
SP070021U00 | S SOCKET BELLWETHER 80506-4121 262P DDR5 | Bellwhether
SP070021S00 | S SOCKET BELLWETHER 80507-4121 262P DDR5 | Bellwhether
SP070018L00 | S SOCKET BELLWETHER 80159-3221 67P NGFF | Bellwhether
SP07001ZAA0 | S SOCKET LOTES APCIA173-P002TC 67P H1.65 NGFF | LOTES
SP070013E00 | S SOCKET BELLWETHER 80152-3221 67P NGFF | Bellwhether

Laptop 16 | DESIGNED BY | DRAWN BY

CHECKED BY | APPROVED BY

THIRD ANGLE PROJECTION | | ISSUED DATE Jan-30-241.000 mm | SCALE | UNIT

DRAWING FILE NAME

Laptop 16 Main Board

1

2

PART NUMBER; DESCRIPTION; SPECIFICATION; MODEL; Jan-30-24; UNLESS SPECIFIED TOLERANCE ARE:; 300 ABOVE :; 20mm BELOW :; ANGLES :; Top view; Bottom view; SCALE 1.000; Pin 1; Pin 1 Location

Laptop 16 | DESIGNED BY | DRAWN BY

CHECKED BY | APPROVED BY

THIRD ANGLE PROJECTION | | ISSUED DATE | SCALE | UNIT

Laptop 16 Main Board

DRAWING FILE NAME

1

2

PART NUMBER; DESCRIPTION; SPECIFICATION; MODEL; UNLESS SPECIFIED TOLERANCE ARE:; 300 ABOVE :; 20mm BELOW :; ANGLES :; Top view; Bottom view; SCALE 1.000; Limit Height

No test point for H=0
(No Solder balls)

Pad area no test point

Laptop 16 | DESIGNED BY | DRAWN BY

CHECKED BY | APPROVED BY

THIRD ANGLE PROJECTION | | ISSUED DATE Jan-30-241.000 mm | SCALE | UNIT

DRAWING FILE NAME
Laptop 16 Main Board

1

2

PART NUMBER; DESCRIPTION; SPECIFICATION; MODEL; UNLESS SPECIFIED TOLERANCE ARE:; 300 ABOVE :; 20mm BELOW :; ANGLES :; Top view; Bottom view; SCALE 1.000; SEE DETAIL A; DETAIL A SCALE 3.000

Laptop 16 | DESIGNED BY | DRAWN BY

CHECKED BY | APPROVED BY

GND Pad area

THIRD ANGLE PROJECTION | | ISSUED DATE Jan-30-241.000 mm | SCALE | UNIT

DRAWING FILE NAME

Laptop 16 Main Board

1

2

20.55 ¹¹⁴.90; ⌀4.40(PTH); ⌀2.50(PTH); ⌀4.40 (PTH); (PTH); ⌀2.70(PTH); ⌀4.20(PTH); ⌀3.70(PTH); ⌀3.90(PTH); 3.70(PTH); 2.80(PTH); ⌀1.20(PTH); PART NUMBER; DESCRIPTION; SPECIFICATION; MODEL; UNLESS SPECIFIED TOLERANCE ARE:; 300 ABOVE :; 20mm BELOW :; ANGLES :; Top view; Bottom view; SCALE 1.000; Outline; Laptop 16 Main Board

Laptop 16 | DESIGNED BY | DRAWN BY

CHECKED BY | APPROVED BY

THIRD ANGLE PROJECTION | | ISSUED DATE Jan-30-241.000 mm | SCALE | UNIT

DRAWING FILE NAME

1

2
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

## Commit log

2024-02-15 Add interface schematic
2024-06-12 Add 3D CAD of the system
2024-06-12 Update README.md for CAD
2025-08-27 Upload one-piece-touchpad files
    [one_piece_touchpad_left_0807.stl, one_piece_touchpad_middle_0807.stl, one_piece_touchpad_right_0807.stl]
2025-08-27 Reversed left and right
    [one_piece_touchpad_left_0807.stl, one_piece_touchpad_right_0807.stl]
2025-08-28 Touchpad: Add suggested print orientation
2025-09-10 Updated geometry to improve reliability
    Carol updated the design of the hooks to improve reliability on 3d printed parts.
    [one_piece_tp_left_0909.stl, one_piece_tp_mid_0909.stl, one_piece_tp_right_0909.stl]
2025-11-12 Add 3d printable case
    [connect_pin_1_11112025.stl, connect_pin_2_11112025.stl, mb_case_bottom_cover_11112025.stl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]
2025-11-12 Update README.md to note Case
2025-11-12 Add case image
2025-11-25 Add 300 Series interface schematic
2025-12-01 Adding a step file version
    [mb_case_assy_11112025.stp]
2026-06-23 Hinges folder
2026-06-23 Add hinge CAD
    [framework_laptop_16_hinge_assy_asm.stp]
